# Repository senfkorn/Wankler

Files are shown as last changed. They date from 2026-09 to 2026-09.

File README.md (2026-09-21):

# Wankler – Kompressionsmessgerät für Wankelmotoren

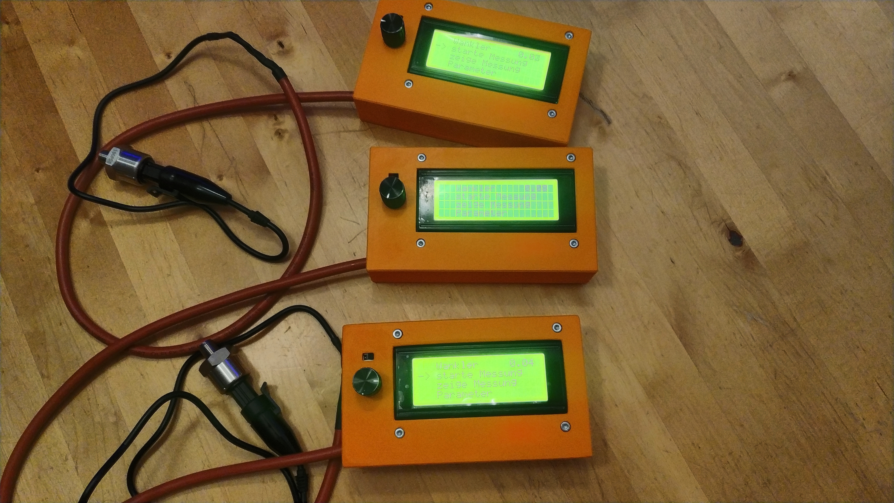
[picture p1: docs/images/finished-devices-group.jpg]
Fertige Messgeräte


Der **Wankler** ist ein mikrocontrollergesteuertes Kompressionsmessgerät für Wankelmotoren. Er misst den Kompressionsdruck aller drei Brennkammern sowie die Motordrehzahl und zeigt beides direkt auf einem LCD-Display an.

## Funktionsweise

Der Mikrocontroller liest das Signal eines Drucksensors mit **1000 Hz** ein. Die Messwerte werden per gleitendem Mittelwert geglättet (die Filterkonstante lässt sich über das Display einstellen). Anschließend wird der sinusförmige Druckverlauf des Wankelmotors analysiert und Minima/Maxima ermittelt: Drei aufeinanderfolgende Maxima entsprechen den Kompressionswerten der drei Brennkammern.

Gleichzeitig wird die zeitliche Differenz zwischen den Maxima gemessen, woraus sich die Motordrehzahl ergibt – ein wichtiger Wert, da der zu erwartende Kompressionsdruck direkt von der Drehzahl abhängt.

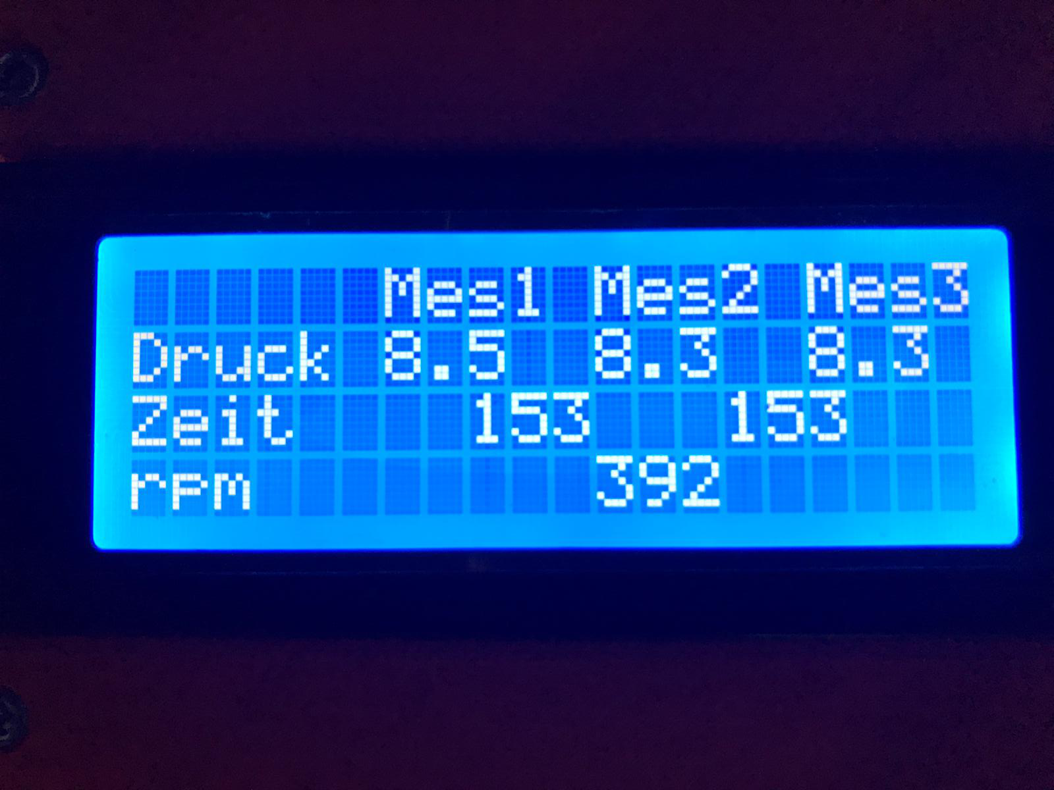
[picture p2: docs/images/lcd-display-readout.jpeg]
LCD-Anzeige einer Messung


## Projektstruktur

| Ordner | Inhalt |
|---|---|
| [`firmware/`](firmware/) | Arduino-Firmware (PlatformIO) + fertig kompilierte `.hex`-Datei |
| [`hardware/`](hardware/) | Schaltplan, Stückliste (BOM) und EasyEDA-Projekt der optionalen Interfaceplatine |
| [`3d-print/`](3d-print/) | Gehäuse als druckfertige `.3mf`- und editierbare `.step`-Datei |
| [`docs/`](docs/) | Baufotos als Montage-Referenz |

## Aufbau eines eigenen Messgeräts

1. **Gehäuse drucken** – siehe [`3d-print/`](3d-print/). `Case.3mf` direkt in den Slicer laden und drucken, `Wankler_v24.step` bei Bedarf im CAD anpassen.
2. **Elektronik besorgen** – Bauteilliste in [`hardware/BOM.xlsx`](hardware/BOM.xlsx), inkl. typischer eBay-Suchbegriffe.
3. **Platine (optional) fertigen lassen** – EasyEDA-Projekt in [`hardware/easyeda/`](hardware/easyeda/) direkt bei JLCPCB bestellbar. Die Platine ist **nicht zwingend nötig**, dient nur der einfacheren Montage. Die ersten Geräte wurden komplett diskret verdrahtet.
4. **Firmware flashen** – entweder die fertige [`firmware/firmware.hex`](firmware/firmware.hex) mit einem Tool wie [XLoader](http://www.hobbytronics.co.uk/download/XLoader.zip) auf den Arduino Nano spielen, oder den Quellcode in [`firmware/src/main.cpp`](firmware/src/main.cpp) mit PlatformIO selbst bauen. Details in [`firmware/README.md`](firmware/README.md).
5. **Zusammenbauen** – eine geschriebene Anleitung gibt es aktuell noch nicht, aber eine bebilderte Referenz aus dem eigenen Bauprozess in [`docs/assembly.md`](docs/assembly.md).

## Sensor-Kalibrierung

Mehrere der verwendeten (chinesischen) Drucksensoren wurden in einem Prüflabor mit hochwertigem Referenz-Messequipment verglichen. Mit der in der Firmware hinterlegten Kalibrierung lag die Abweichung durchweg unter 0,1 bar – daher wurde auf eine nutzerseitige Kalibrierung über das Display verzichtet.

## Platine gefällig?

Wer eine fertig bestückte Interfaceplatine möchte statt selbst zu bestellen: einfach beim Projektautor melden, es liegen noch ein paar Exemplare bereit.

## Mitmachen

Eine schriftliche Montageanleitung fehlt bislang – wer sich zutraut, eine zu schreiben, ist herzlich zu einem Pull Request eingeladen. Auch sonstige Verbesserungen an Firmware, Platine oder Gehäuse sind willkommen.

## Lizenz

Dieses Projekt (Firmware, Hardware-Design und Gehäuse-Konstruktion) steht unter der [MIT-Lizenz](LICENSE).

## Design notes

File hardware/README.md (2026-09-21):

# Hardware / Elektronik

Elektronik-Unterlagen für die Wankler-Interfaceplatine.

## Inhalt

| Datei | Beschreibung |
|---|---|
| `Schematic.pdf` | Schaltplan der Interfaceplatine (Rev. 1.0) |
| `BOM.xlsx` | Stückliste mit typischen eBay-Suchbegriffen zur Beschaffung der Bauteile |
| `easyeda/` | EasyEDA-Quelldateien (Schaltplan + Platinenlayout) |

## Wichtiger Hinweis

**Die Interfaceplatine ist optional.** Sie dient nur der einfachen Montage. Die ersten Messgeräte wurden vollständig diskret verdrahtet, ganz ohne PCB. Wer trotzdem eine Platine möchte, kann sich gerne beim Projektautor melden – es sind noch ein paar Exemplare vorhanden.

## Platine selbst fertigen lassen (EasyEDA / JLCPCB)

1. Bei [EasyEDA](https://easyeda.com) einen neuen Account/Workspace öffnen.
2. Über die Menüleiste: **Dokument → Öffnen → EasyEDA-Quelle** und die Datei `easyeda/PCB_Wankler_Interface.json` bzw. `easyeda/Schematic_Wankler.json` laden.
3. Über **Fertigen → PCB fertigen** direkt an JLCPCB übergeben.

## Bauteile

Die Bauteilliste (`BOM.xlsx`) enthält neben den technischen Bezeichnungen auch gängige eBay-Suchbegriffe, mit denen sich die Komponenten leicht wiederfinden lassen.

## Sensor-Kalibrierung

Mehrere der verwendeten (chinesischen) Drucksensoren wurden in einem Prüflabor mit hochwertigem Referenz-Messequipment (mehrere 1000 € Anschaffungswert) verglichen. Mit der in der Firmware hinterlegten Kalibrierung lag die Abweichung bei allen getesteten Sensoren unter 0,1 bar. Aus diesem Grund wurde auf eine nutzerseitige Kalibrierung über das Display verzichtet.

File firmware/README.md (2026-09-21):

# Firmware

Firmware für den Arduino Nano im Wankler-Messgerät, erstellt mit [PlatformIO](https://platformio.org/).

## Inhalt

| Datei | Beschreibung |
|---|---|
| `src/main.cpp` | Quellcode der Firmware |
| `platformio.ini` | PlatformIO-Projektkonfiguration (siehe Hinweis unten) |
| `firmware.hex` | Fertig kompilierte Firmware zum direkten Flashen |

## Firmware flashen

**Option A – fertige .hex-Datei (am einfachsten)**

Mit einem Tool wie [XLoader](http://www.hobbytronics.co.uk/download/XLoader.zip) kann `firmware.hex` direkt auf den Arduino Nano geflasht werden. Kein Compiler nötig.

**Option B – aus dem Quellcode bauen**

```bash
# PlatformIO CLI installieren, falls noch nicht vorhanden
pip install platformio

# Im firmware/-Ordner:
pio run --target upload
```

> **Hinweis:** `platformio.ini` war im Originalprojekt nicht dabei und wurde anhand der in `main.cpp` eingebundenen Bibliotheken (`LiquidCrystal_I2C`, `RotaryEncoder`, `OneButton`) sowie der Zielhardware (Arduino Nano / ATmega328) rekonstruiert. Bitte die Bibliotheksversionen bei Bedarf anpassen, falls es beim Bauen zu Fehlern kommt.

## Funktionsweise

Die Firmware liest das Signal eines Drucksensors mit 1000 Hz ein, glättet es per gleitendem Mittelwert und erkennt darin die Maxima des sinusförmigen Druckverlaufs eines Wankelmotors. Drei aufeinanderfolgende Maxima entsprechen den Kompressionswerten der drei Brennkammern. Aus dem zeitlichen Abstand der Maxima wird zusätzlich die Motordrehzahl berechnet.

Bedienung erfolgt über ein I2C-LCD (20x4) und einen Drehencoder mit Taster. Parameter (Schwellwert, Timeout, Filter) werden im EEPROM gespeichert und können über das Menü angepasst werden.

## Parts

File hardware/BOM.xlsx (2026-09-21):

Anzahl | Name | Ebay seach | Comment
10 | PCB |  | JLCpcb
10 | Arduino Nano | USB Nano V3.0 ATmega328P CH340G 5V 16M | 5v version is important
10 | Rotary Encoder | KY-040 | look for a bundle with knob
10 | Switch | small spdt
10 | BatterieClip | 9v batterie clip 15cm | 15cm cable length are important
10 | LCD | 2004 lcd i2c
10 | PressureTransmiter | 1/8NPT Stainless Steel Pressure 150psi
10 | 9V Block
10 | Upper Case |  | 3d print
10 | Lower Case |  | 3d print
10 | BatterieBezel |  | 3d print
10 | 1 m sensor cable | sihf 3x0.5
10 | JST XH 3 pin connector | JST XH 3 pin connector
10 | JST XH 3 pin plug | JST XH 3 pin plug
10 | JST XH 5 pin connector | JST XH 5 pin connector
10 | JST XH 5 pin Kabel mit plug | JST XH 5 pin Kabel mit plug
10 | JST XH 4 pin connector | JST XH 4 pin connector
10 | JST XH 4 pin Kabel mit plug | JST XH 4 pin Kabel mit plug
10 | JST XH 2 pin connector | JST XH 2 pin connector
10 | JST XH 2 pin Kabel mit plug | JST XH 2 pin Kabel mit plug
10 | JST XH 2 pin plug + connector Set | JST XH 2 pin plug + connector Set

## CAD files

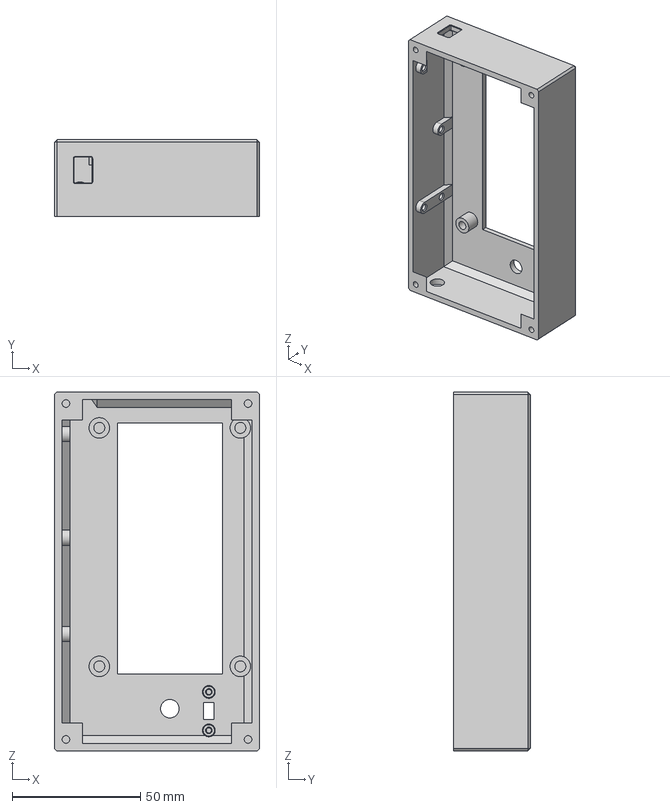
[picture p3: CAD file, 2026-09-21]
3d-print/Wankler_v24.step
80.0 x 30.0 x 140.0 mm

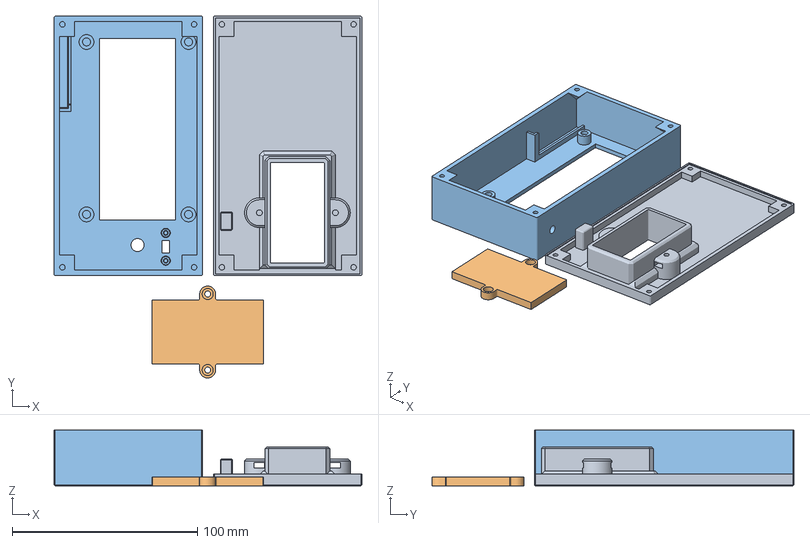
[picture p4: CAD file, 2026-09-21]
3d-print/Case.3mf
166.0 x 195.2 x 30.0 mm
Deckel.stl
BatterieDeckel.stl
Base.stl

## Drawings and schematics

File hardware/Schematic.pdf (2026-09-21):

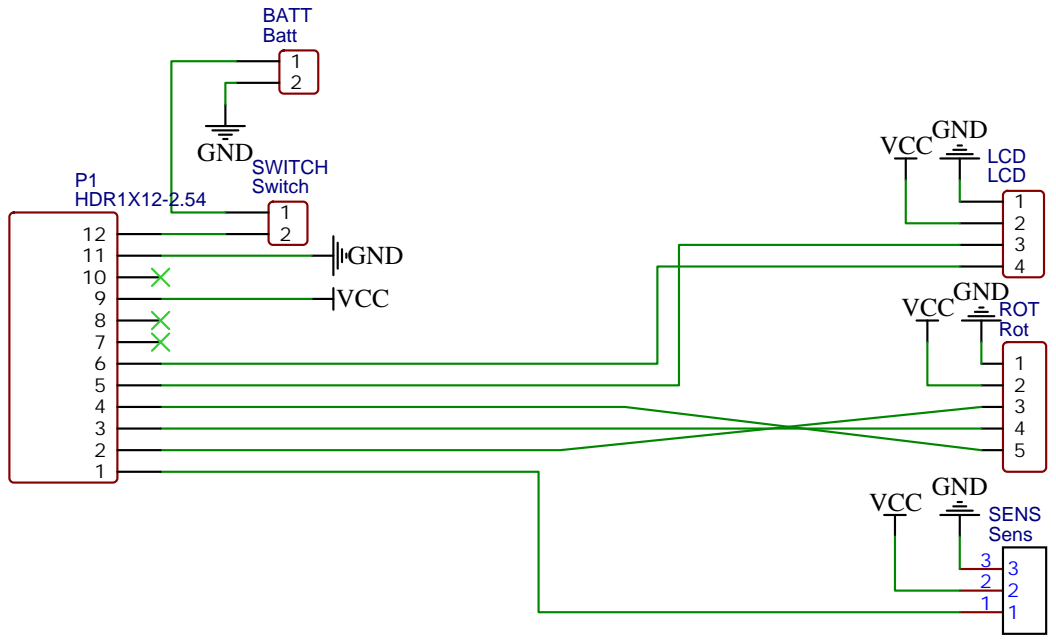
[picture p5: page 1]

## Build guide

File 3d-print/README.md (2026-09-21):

# 3D-Druck – Gehäuse

3D-Druckdateien für das Gehäuse des Wankler-Messgeräts.

## Inhalt

| Datei | Beschreibung |
|---|---|
| `Case.3mf` | Druckfertige Datei inkl. Druckeinstellungen, zum direkten Import in den Slicer (z. B. PrusaSlicer, Bambu Studio) |
| `Wankler_v24.step` | STEP-Datei des Gehäuses, editierbar in jedem gängigen CAD-Programm (Fusion 360, FreeCAD, SolidWorks, ...) |

## Verwendung

- **Nur drucken:** `Case.3mf` direkt im Slicer öffnen und drucken.
- **Gehäuse anpassen:** `Wankler_v24.step` in ein CAD-Programm importieren, bearbeiten und als neue `.3mf`/`.stl` für den Slicer exportieren.

## Material & Druckempfehlung

In den Baufotos (siehe [`../docs/images`](../docs/images)) sind fertig gedruckte Gehäuse in orange und rot zu sehen – Standard-PLA hat sich dabei bewährt. Konkrete Slicer-Einstellungen (Layerhöhe, Infill, Support) sind in der `Case.3mf` bereits hinterlegt.

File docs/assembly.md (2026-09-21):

# Montage – Bildreferenz

> Eine geschriebene Schritt-für-Schritt-Anleitung gibt es aktuell noch nicht. Als Orientierung dient stattdessen diese Bildergalerie aus dem Bauprozess mehrerer Messgeräte. Wer eine schriftliche Anleitung beisteuern möchte: sehr gerne per Pull Request!

## 1. Kabel & Stecker vorbereiten

Alle Komponenten werden mit passenden Steckverbindern konfektioniert, damit sich das Gerät ohne Löten am Gehäuse zusammenstecken lässt.

| | |
|---|---|
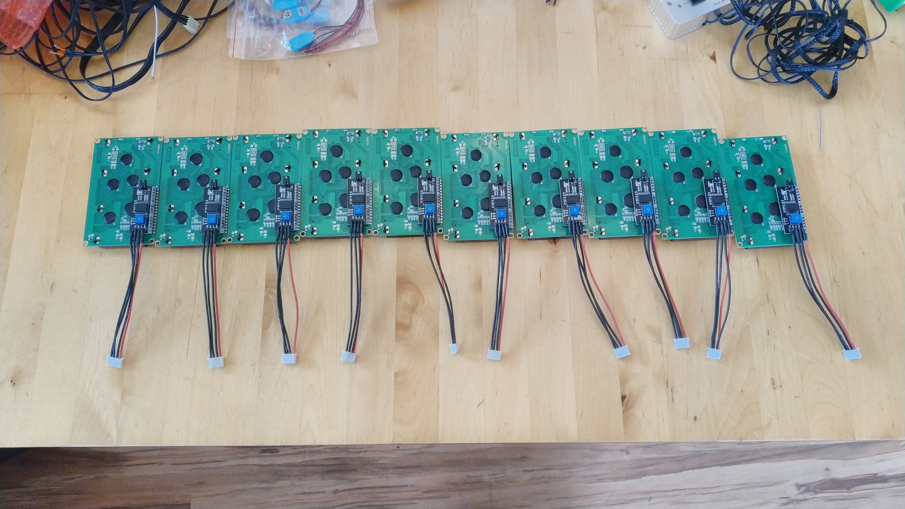
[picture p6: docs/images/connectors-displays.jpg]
Displays mit Stecker
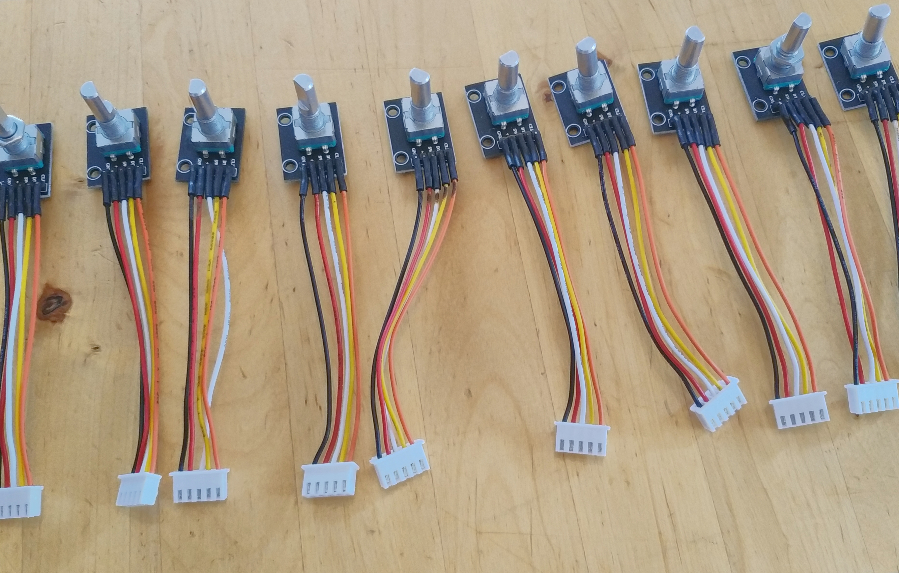
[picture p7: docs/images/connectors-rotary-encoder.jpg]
Rotary Encoder mit Stecker
|  |  |
| LCD-Displays mit JST-Steckern | Drehencoder mit JST-Stecker |
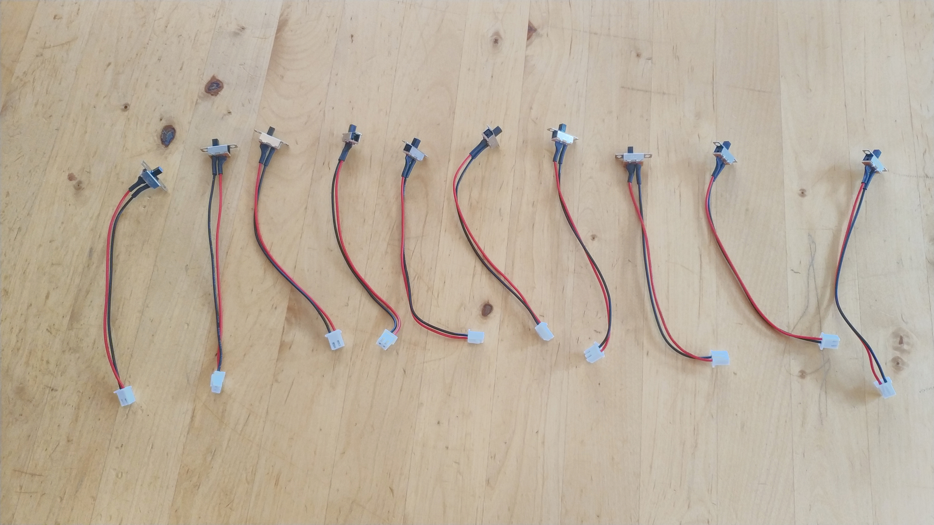
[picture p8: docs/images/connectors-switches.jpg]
Schalter mit Stecker
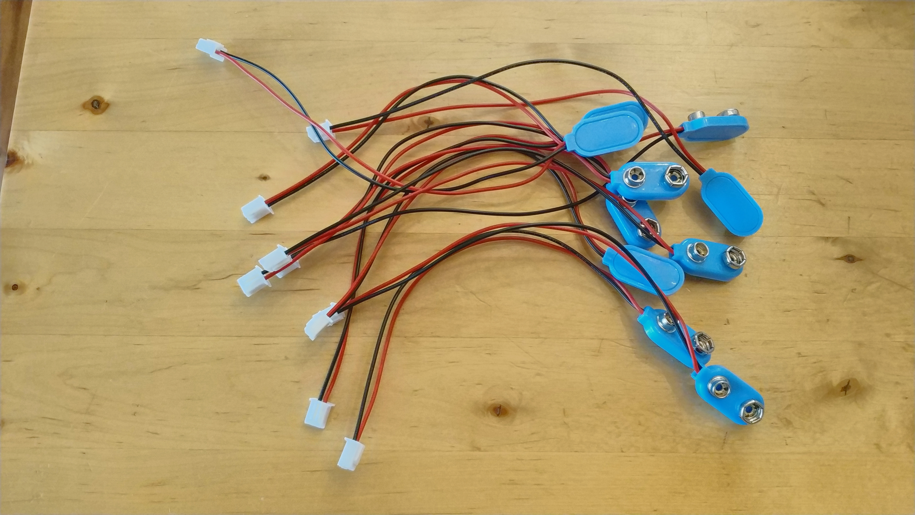
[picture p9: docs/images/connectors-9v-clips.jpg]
9V-Clips mit Stecker
|  |  |
| Ein-/Ausschalter mit Stecker | 9V-Batterieclips mit Stecker |
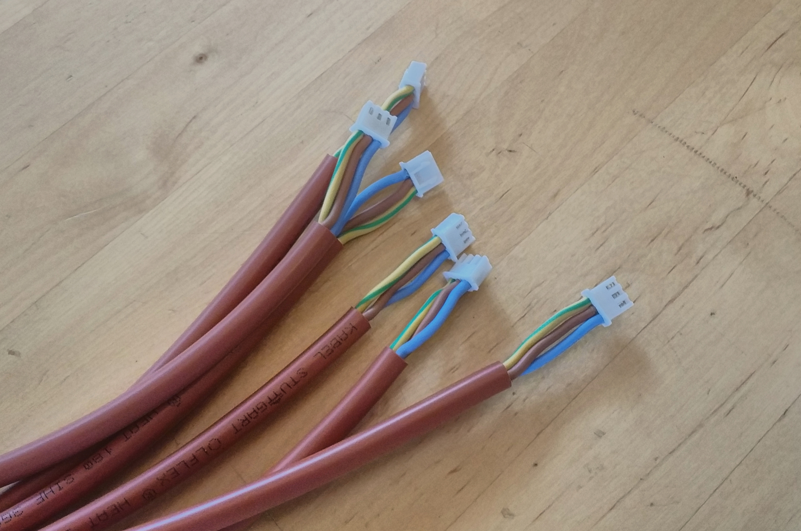
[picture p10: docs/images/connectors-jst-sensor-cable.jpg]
JST-Stecker an Sensorleitung
|  | |
| JST-Stecker an der Sensorleitung (Drucksensor) | |

## 2. Interfaceplatine bestücken & testen

Die optionale Interfaceplatine vereinfacht die Verkabelung erheblich. Vor der Serienfertigung wurde der Aufbau erst mit einer Papierschablone, dann mit realen Steckern getestet.

| | |
|---|---|
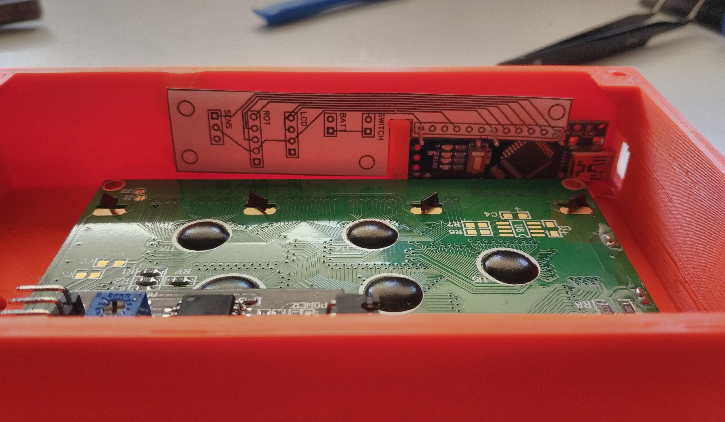
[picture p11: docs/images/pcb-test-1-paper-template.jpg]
Erster Platinentest mit Papier
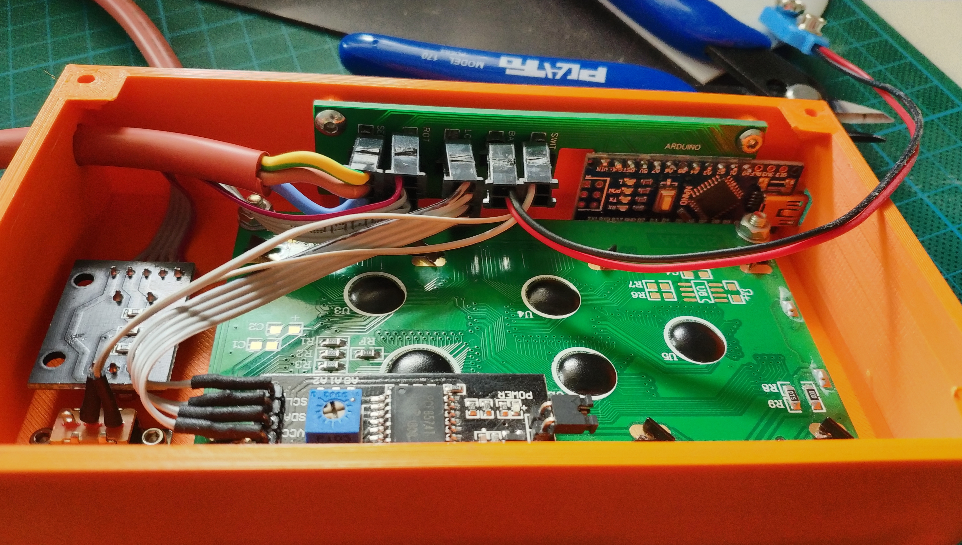
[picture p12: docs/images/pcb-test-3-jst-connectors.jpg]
Dritter Platinentest mit JST-Steckern
|  |  |
| Erster Test: Steckerbelegung auf Papier geprüft | Dritter Test: von Molex- auf JST-Stecker gewechselt |
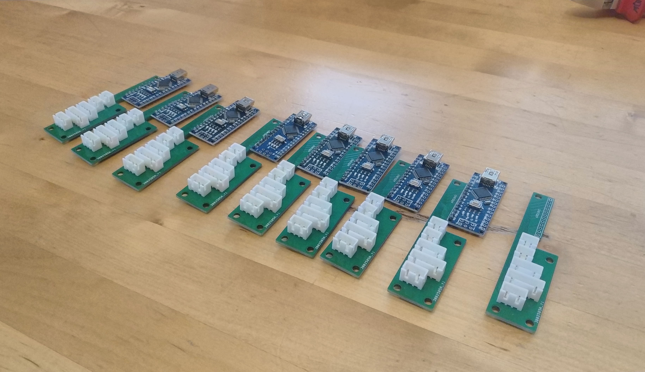
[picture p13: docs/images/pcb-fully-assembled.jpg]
Platinen voll bestückt
|  | |
| Mehrere fertig bestückte Interfaceplatinen | |

## 3. Endmontage im Gehäuse

Zwei Varianten sind entstanden: mit Interfaceplatine (empfohlen, einfacher) und komplett diskret verdrahtet (die ersten gebauten Geräte).

| | |
|---|---|
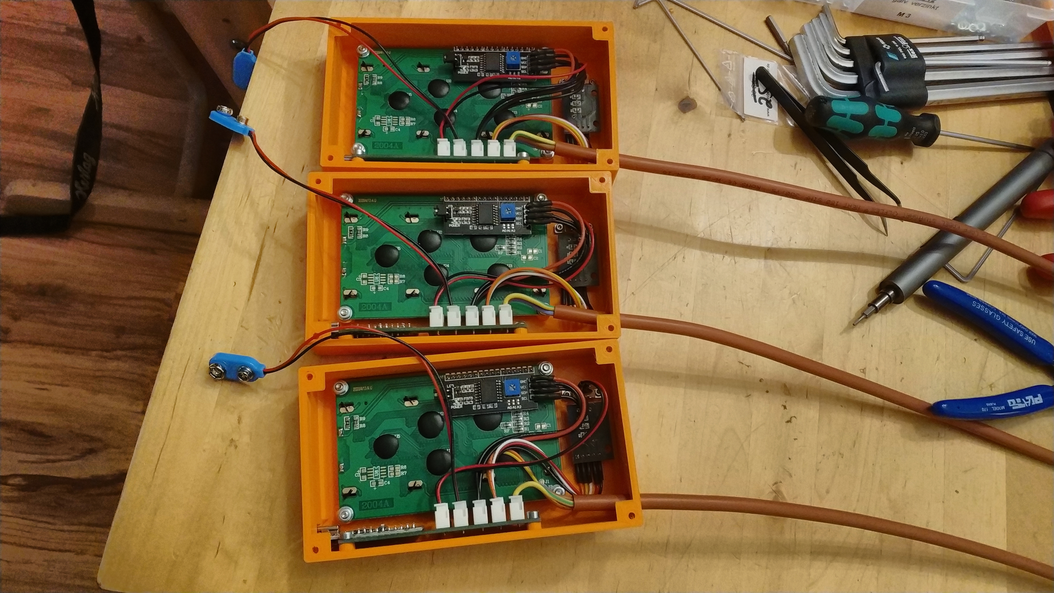
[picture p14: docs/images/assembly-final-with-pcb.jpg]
Fertig montiert mit Platine
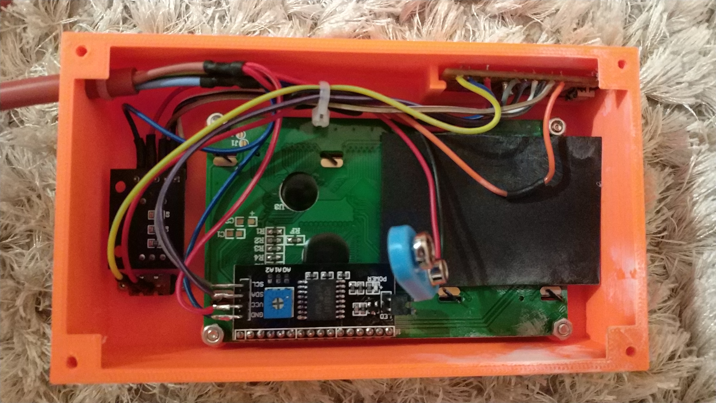
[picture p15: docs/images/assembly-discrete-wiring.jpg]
Messgerät mit diskreter Verdrahtung
|  |  |
| Mit Interfaceplatine montiert | Ohne Platine, diskret verdrahtet |

## 4. Fertige Geräte

| | |
|---|---|
| Fertige Messgeräte | LCD-Anzeige während einer Messung |
| Mehrere fertige Messgeräte, angeschlossen an den Drucksensor | LCD-Anzeige nach einer Messung (Druck, Zeit, Drehzahl) |

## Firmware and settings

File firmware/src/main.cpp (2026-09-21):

#include <Arduino.h>

#define Messungen 10

#include <Wire.h> 
#include <LiquidCrystal_I2C.h>
#include <RotaryEncoder.h>
#include <EEPROM.h>
#include "OneButton.h"

LiquidCrystal_I2C lcd(0x27,20,4);  // set the LCD address to 0x27 for a 16 chars and 2 line display // SCL = A5 // SDA = A4
RotaryEncoder encoder(A2, A3);
OneButton button(A1, true);


void ButtonClick();
void showTopMenu();
void showParameterMenu();
void doMessung();
void showMessung();
void changeThreshold();
void changeTimeout();
void changeFilter();
template <class T> int EEPROM_writeAnything(int ee, const T& value);
template <class T> int EEPROM_readAnything(int ee, T& value);
float mapfloat(float x, float in_min, float in_max, float out_min, float out_max);
float getValue(int Pin);

bool Init = true;
const int analogInPin = A0;
float sensorValue = 0.0; 
float lowestValue = 0.0;
float highestValue = 0.0;
unsigned long lasttick = 0;
float Max[Messungen];
float lastValue;
unsigned long TimeStamp[Messungen];
int Index= 0;
float Threshold = 2.0;
boolean Clicked = false;
int MenuItem = 0;
int MenuItemOld = 0;
int EncoderAct = 0;
int EncoderOld = 0;
int Filter = 10;
unsigned long StartMessung = 0;
unsigned long TimeoutStamp = 0;
unsigned long Timeout = 60000;
const int ledPin =  LED_BUILTIN;
int ledState = LOW;
unsigned long previousMillis = 0;
const long interval = 1000;  

//ISR
ISR(PCINT1_vect) {
  encoder.tick();
  button.tick();
}

void setup() {
  Serial.begin(115200);    // start the serial port
  pinMode(ledPin, OUTPUT);
  // You may have to modify the next 2 lines if using other pins than A2 and A3
  PCICR  |= (1 << PCIE1);    // This enables Pin Change Interrupt 1 that covers the Analog input pins or Port C.
  PCMSK1 |= (1 << PCINT9) | (1 << PCINT10) | (1 << PCINT11);  // This enables the interrupt for pin 1, pin 2 and 3 of Port C.

  button.attachClick(ButtonClick);

  lcd.init();                      // initialize the lcd 
  lcd.backlight();
  lcd.clear();

//read parameter from eeprom if button is not pressed on startup
  if(digitalRead(A1)){ 
    EEPROM_readAnything(10, Timeout);
    EEPROM_readAnything(20, Threshold);
    EEPROM_readAnything(30, Filter);
  }
//wait until button is released
  while(!digitalRead(A1)) {
  }
}

void loop() {

encoder.tick();
button.tick();

if (MenuItem != MenuItemOld){
 lcd.clear();
 encoder.setPosition(0);
 MenuItemOld = MenuItem;
}

switch (MenuItem) {
  case 0: //top menu
    showTopMenu();
    break;
  case 1: //zeige Messung
    showMessung();
    break;
  case 2: //parameter menu
    showParameterMenu();
    break;
  case 3: //change threshold
    changeThreshold();
    break;
  case 4: //change timeout
    changeTimeout();
    break;
  case 5: //change timeout
    changeFilter();
    break;
  default:
    // statements
    break;
}

  if (Clicked && !Init){
    switch (MenuItem) {
    case 0: //top menu
      if (encoder.getPosition()== 0){
        doMessung();
      } 
      if (encoder.getPosition()== 1){
        MenuItem = 1; //goto show measurement
      } 
      if (encoder.getPosition()== 2){
        MenuItem = 2; //goto parameter menu
      } 
      break;
    case 1: //measurement
      MenuItem = 0; //goto top menu
      break;
      case 2: //parameter menu
      if (encoder.getPosition()== 0){
        MenuItem = 3; //goto change threshold
      } 
      if (encoder.getPosition()== 1){
        MenuItem = 4; //goto change timeout
      } 
      if (encoder.getPosition()== 2){
        MenuItem = 5;//goto top menu
      }
      if (encoder.getPosition()== 3){
        MenuItem = 0;//goto top menu
      }
      break;
    default:
    break;
    }
  }

Clicked = false;

//reset Init value and allow normal operation
if (digitalRead(A1) && Init){
  Init = false;
}

unsigned long currentMillis = millis();
if (currentMillis - previousMillis >= interval) {
  previousMillis = currentMillis;
  if (ledState == LOW) {
    ledState = HIGH;
  } else {
    ledState = LOW;
  }
  digitalWrite(ledPin, ledState);
}

}

//button clicked interrupt
void ButtonClick(){
  Clicked = true;

}

void doMessung(){

// init messung
  lcd.clear();
  lcd.setCursor(2,1);
  lcd.print("Messung laeuft");
  Index = 0;
  for (int i = 0; i < Messungen; i++){
    Max[i] = 0;
    TimeStamp[i] = 0;
  }
  TimeoutStamp = millis();


  
  
  do {

    //wait for positive edge 
    lowestValue =  getValue(analogInPin);
    do{
      sensorValue = getValue(analogInPin);
      if (lowestValue > sensorValue){
        lowestValue = sensorValue;
      }
    }while(sensorValue - lowestValue < Threshold && millis() - TimeoutStamp < Timeout);
    //Serial.println("Pos edge found");
    
    //wait for negative edge 
    highestValue =  getValue(analogInPin);
    do{
      sensorValue = getValue(analogInPin);
      if (highestValue < sensorValue){
        highestValue = sensorValue;
      }
    }while(highestValue - sensorValue < Threshold && millis() - TimeoutStamp < Timeout);
    //Serial.println("Neg edge found");
    //save highest value
    Max[Index] = highestValue;
    TimeStamp[Index] = millis();
    Index++;
  }while (Index < Messungen && millis() - TimeoutStamp < Timeout);

  if (millis() - TimeoutStamp >= Timeout){
    lcd.clear();
    lcd.setCursor(6,2);
    lcd.print("Timeout");
    delay(10000);
    MenuItem = 0;
  }else{
    lcd.clear();
    lcd.setCursor(6,2);
    lcd.print("fertig");
    delay(1000);
    MenuItem = 1;
  }


}

void showTopMenu(){

static unsigned long actTick = 0;
static unsigned long lastTick = 0;

  EncoderAct = encoder.getPosition();
  if (encoder.getPosition() < 0) {
    encoder.setPosition(0);
    EncoderAct = 0;
  }
  if (encoder.getPosition() > 2) {
    encoder.setPosition(2);
    EncoderAct = 2;
  }

  if (EncoderAct != EncoderOld){
    lcd.setCursor(0,1);
    lcd.print("  ");
    lcd.setCursor(0,2);
    lcd.print("  ");
    lcd.setCursor(0,3);
    lcd.print("  ");
    EncoderOld = EncoderAct;
  }

  lcd.setCursor(3,0);
  lcd.print("Wankler");
  lcd.setCursor(3,1);
  lcd.print("starte Messung");
  lcd.setCursor(3,2);
  lcd.print("zeige Messung");
  lcd.setCursor(3,3);
  lcd.print("Parameter");
  lcd.setCursor(0,EncoderAct + 1);
  lcd.print("->");

  //show actual value at the corner
actTick = millis();
if (actTick - lastTick > 100 && MenuItem == 0){
  lastTick = actTick;
  lcd.setCursor(19,0);
  lcd.print(" ");
  lcd.setCursor(15,0);
  lcd.print(getValue(analogInPin), 2);
}
}

void showParameterMenu(){

  EncoderAct = encoder.getPosition();
  if (encoder.getPosition() < 0) {
    encoder.setPosition(0);
    EncoderAct = 0;
  }
  if (encoder.getPosition() > 3) {
    encoder.setPosition(3);
    EncoderAct = 3;
  }

  if (EncoderAct != EncoderOld){
    lcd.setCursor(0,1);
    lcd.print("  ");
    lcd.setCursor(0,2);
    lcd.print("  ");
    lcd.setCursor(0,3);
    lcd.print("  ");
    EncoderOld = EncoderAct;
  }
  lcd.setCursor(0,0);
  lcd.print("Parameter");
  lcd.setCursor(16,0);
  lcd.print("v1.3");
  if (EncoderAct < 3){
    lcd.setCursor(3,1);
    lcd.print("Schwelle aendern ");
    lcd.setCursor(3,2);
    lcd.print("Timeout aendern  ");
    lcd.setCursor(3,3);
    lcd.print("Filter aendern   ");
    lcd.setCursor(0,EncoderAct + 1);
    lcd.print("->");
  }else{
    lcd.setCursor(3,1);
    lcd.print("Timeout aendern  ");
    lcd.setCursor(3,2);
    lcd.print("Filter aendern   ");
    lcd.setCursor(3,3);
    lcd.print("zurueck          ");
    lcd.setCursor(0,3);
    lcd.print("->");
  }
}

void showMessung(){
      lcd.setCursor(6,0);
      lcd.print("Mes1");
      lcd.setCursor(11,0);
      lcd.print("Mes2");
      lcd.setCursor(16,0);
      lcd.print("Mes3");

      lcd.setCursor(0,1);
      lcd.print("Druck");
      lcd.setCursor(6,1);
      lcd.print(Max[Messungen -3], 1);
      lcd.setCursor(11,1);
      lcd.print(Max[Messungen -2], 1);
      lcd.setCursor(16,1);
      lcd.print(Max[Messungen -1], 1);


      float time1 = TimeStamp[Messungen -2]-TimeStamp[Messungen -3];
      float time2 = TimeStamp[Messungen -1]-TimeStamp[Messungen -2];

      lcd.setCursor(0,2);
      lcd.print("Zeit");
      lcd.setCursor(8,2);
      lcd.print(time1,0);
      lcd.setCursor(14,2);
      lcd.print(time2,0);
      lcd.setCursor(0,3);
      if (time2 > 0){
        lcd.print("rpm");
        lcd.setCursor(11,3);
        lcd.print((1.0 / (time2 / 1000.0))*60.0 ,0);
      }
      

}

void changeTimeout(){
RotaryEncoder::Direction encoderMovement;
  lcd.clear();
  lcd.setCursor(0,0);
  lcd.print("Timeout");
  lcd.setCursor(6,2);
  lcd.print(Timeout/1000);
  lcd.setCursor(15,2);
  lcd.print("sek");
  encoderMovement = encoder.getDirection();
  do{
  encoderMovement = encoder.getDirection();
    if (encoderMovement !=  RotaryEncoder::Direction::NOROTATION){
      Timeout += (float)encoderMovement * 1000;
      if (Timeout > 20000){
        Threshold = 20000;
      }else if(Timeout < 1000){
        Timeout = 1000;
      }
      lcd.clear();
      lcd.setCursor(0,0);
      lcd.print("Timeout");
      lcd.setCursor(6,2);
      lcd.print(Timeout/1000);
      lcd.setCursor(15,2);
      lcd.print("sek");
  }
  button.tick();
  }while(!Clicked);
  MenuItem = 2; //goto parameter menu
  Clicked = false;
  EEPROM_writeAnything(10, Timeout);
}

void changeThreshold(){
  RotaryEncoder::Direction encoderMovement;
  lcd.clear();
  lcd.setCursor(0,0);
  lcd.print("Schwellwert");
  lcd.setCursor(6,2);
  lcd.print(Threshold,1);
  lcd.setCursor(15,2);
  lcd.print("bar");
  encoderMovement = encoder.getDirection();
  do{
  encoderMovement = encoder.getDirection();
    if (encoderMovement !=  RotaryEncoder::Direction::NOROTATION){
      Threshold += (float)encoderMovement / 10.0;
      if (Threshold > 5.0){
        Threshold = 5.0;
      }else if(Threshold < 0.1){
        Threshold = 0.1;
      }
      lcd.clear();
      lcd.setCursor(0,0);
      lcd.print("Schwellwert");
      lcd.setCursor(6,2);
      lcd.print(Threshold,1);
      lcd.setCursor(15,2);
      lcd.print("bar");
  }
  button.tick();
  }while(!Clicked);
  MenuItem = 2; //goto parameter menu
  Clicked = false;
  EEPROM_writeAnything(20, Threshold);
}

void changeFilter(){
RotaryEncoder::Direction encoderMovement;
  lcd.clear();
  lcd.setCursor(0,0);
  lcd.print("Filter");
  lcd.setCursor(6,2);
  lcd.print(Filter / 10);
  lcd.setCursor(15,2);
  lcd.print("ms");
  encoderMovement = encoder.getDirection();
  do{
  encoderMovement = encoder.getDirection();
    if (encoderMovement != RotaryEncoder::Direction::NOROTATION){
      Filter += (float)encoderMovement * 10;
      if (Filter > 32767){
        Filter = 32767;
      }else if(Filter < 1){
        Filter = 1;
      }
      lcd.clear();
      lcd.setCursor(0,0);
      lcd.print("Filter");
      lcd.setCursor(6,2);
      lcd.print(Filter / 10);
      lcd.setCursor(15,2);
      lcd.print("ms");
  }
  button.tick();
  }while(!Clicked);
  MenuItem = 2; //goto parameter menu
  Clicked = false;
  EEPROM_writeAnything(30, Filter);
}


float getValue(int Pin){
  float Value = 0;
  Filter = constrain(Filter, 1, 32767);
  for(int i = 0; i < Filter; i++){
    Value += analogRead(analogInPin);
  }
  Value = Value / Filter;

  return(mapfloat(Value,100.0, 900.0, 0.0 , 10.0));

}


template <class T> int EEPROM_writeAnything(int ee, const T& value){
    const byte* p = (const byte*)(const void*)&value;
    unsigned int i;
    for (i = 0; i < sizeof(value); i++)
          EEPROM.write(ee++, *p++);
    return i;
}

template <class T> int EEPROM_readAnything(int ee, T& value){
    byte* p = (byte*)(void*)&value;
    unsigned int i;
    for (i = 0; i < sizeof(value); i++)
          *p++ = EEPROM.read(ee++);
    return i;
}

float mapfloat(float x, float in_min, float in_max, float out_min, float out_max)
{
 return (x - in_min) * (out_max - out_min) / (in_max - in_min) + out_min;
}
